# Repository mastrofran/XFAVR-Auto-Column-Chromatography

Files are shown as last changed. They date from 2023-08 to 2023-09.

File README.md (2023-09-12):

<p align="center">
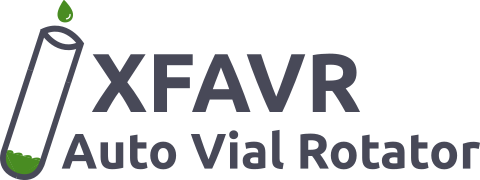
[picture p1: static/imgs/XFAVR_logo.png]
    
</p>
<br>

#### What is it?
XFAVR (Xander and Francesco's Auto Vial Rotator) is a column chromatography device written in C++ and controlled using a programmable microcontroller, such as an Arduino. This device can automatically rotate vials for fractionated liquid collected at a predefined rate of rotation and is primarily used to convert manual silica gel chromatography columns into automated pieces of equipment for research labs.

#### Who can use this?
Absolutely anyone. By following the detailed [**documentation**](https://xfavr.org), anyone can automate fractionated vial collection off of a manual silica column (or any other device that requires manual capture of fractionated liquid using vials).

#### What is involved?
As outlined in the [**documentation**](https://xfavr.org), this device can be built in a few hours using a combination of 3D printing, microcontroller assembly, and software installation.

# Software:

### Install:

#### Project Files:
To begin, please clone this repository using the following command:
```
git clone https://github.com/mastrofran/XFAVR-Auto-Column-Chromatography.git
```

- The [**XFAVR program**](/Code/XFAVR_Code/XFAVR_Code.ino) that runs on the programmable microcontroller to control the device is located in the [Code/XFAVR_Code](/Code/XFAVR_Code) subfolder and was written using C++.

#### Arduino Program:
Download the [official Arduino software](https://www.arduino.cc/en/software) for your computer operating system.

- The recommended way to run the XFAVR program on an programmable microcontroller is to download the official programmable microcontroller program for your chosen computer operating system. This program is used to communicate with programmable microcontroller microcontroller via a computer. Detailed instructions on how to use this program are provided in the documentation.

#### Cura Slicer:
Download the [official Cura Slicer](https://ultimaker.com/software/ultimaker-cura/) for your computer operating system.

- A 3D slicer program is needed to convert the XFAVR device STL files to gcode, which the 3D printer uses as a set of instructions for printing. Detailed instructions on how to use this program are provided in the [**documentation**](https://xfavr.org).

# Hardware:
A list of materials needed for this project are located in the [**documentation**](https://xfavr.org). 

Notes:
- Any microcontroller can be used for this project in theory, however the [Elegoo MEGA R3](https://www.amazon.com/ELEGOO-ATmega2560-ATMEGA16U2-Arduino-Compliant/dp/B01H4ZDYCE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) microcontroller is the recommended microcontroller for this project due to the number of available Digital I/O and Analog Input Pins.
- A 3D printer is used to print the parts. Any 3D printer will do as long as the printer bed dimensions can fit the parts. We used the [Ender-5 Plus](https://www.creality.com/products/ender-5-plus-3d-printer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) and the [Ender-3 v2 3D](https://www.creality.com/products/ender-3-v2-3d-printer-csco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)  printers for this project printer for this project.

⚠️ **WARNING: Do not change the dimensions of any part contained in the 3D printer STL files or the pieces may not fit together during assembly.**

# Documentation:
Official documentation is located here: [**DOCS**](https://xfavr.org)  

There are 3 main components to this project:

1. 3D printed components and assembly
2. Microcontroller assembly
3. Installing the XFAVR software onto the microcontroller

Detailed instructions are outlined in the [**documentation**](https://xfavr.org).

## Support:
Having trouble? Create an issue [here](https://github.com/mastrofran/XFAVR-Auto-Column-Chromatography/issues/new).

## Contributors:
Francesco Mastrocinque: [Github](https://github.com/mastrofran) | [LinkedIn](https://www.linkedin.com/in/francesco-mastrocinque)

Xander Wilcox: [Github](https://github.com/XanderWilcox) | [LinkedIn](https://www.linkedin.com/in/xander-wilcox-01321a21b)

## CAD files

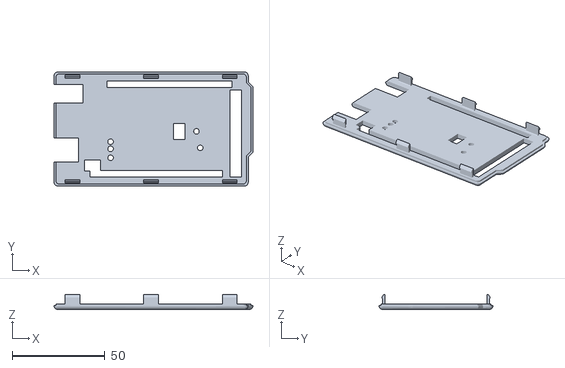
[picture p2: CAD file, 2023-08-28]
3D Printing Files/MicrocontrollerLid.stl
107.1 x 61.3 x 8.00

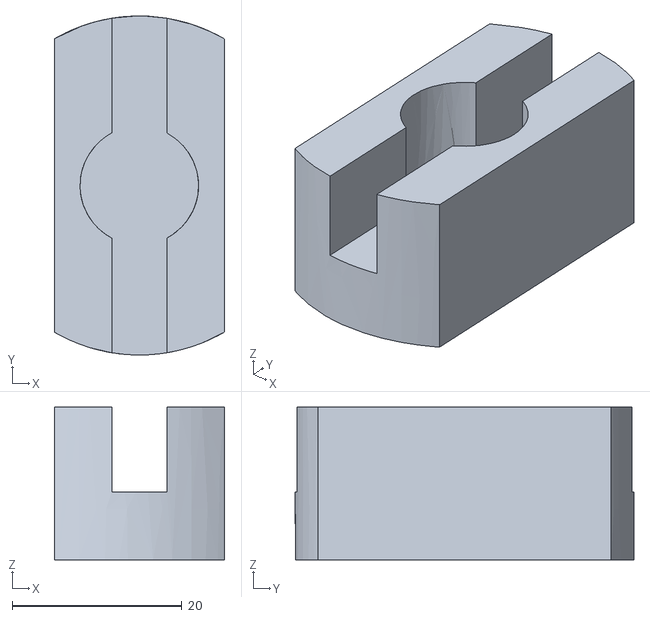
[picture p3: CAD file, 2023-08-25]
3D Printing Files/SingleStepperMotorAdapter.stl
20.1 x 40.0 x 18.0

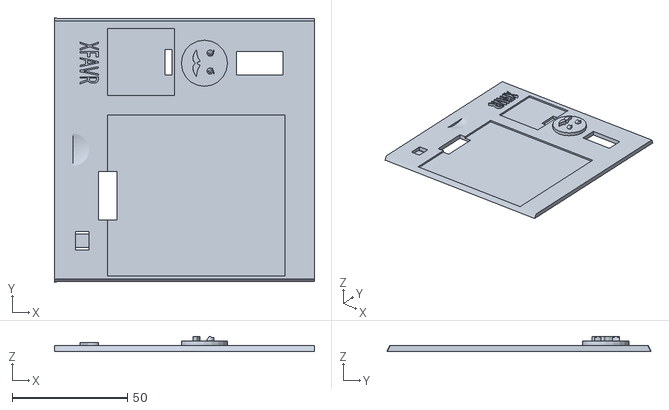
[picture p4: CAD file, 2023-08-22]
3D Printing Files/CaseLid.stl
112.8 x 114.8 x 6.50

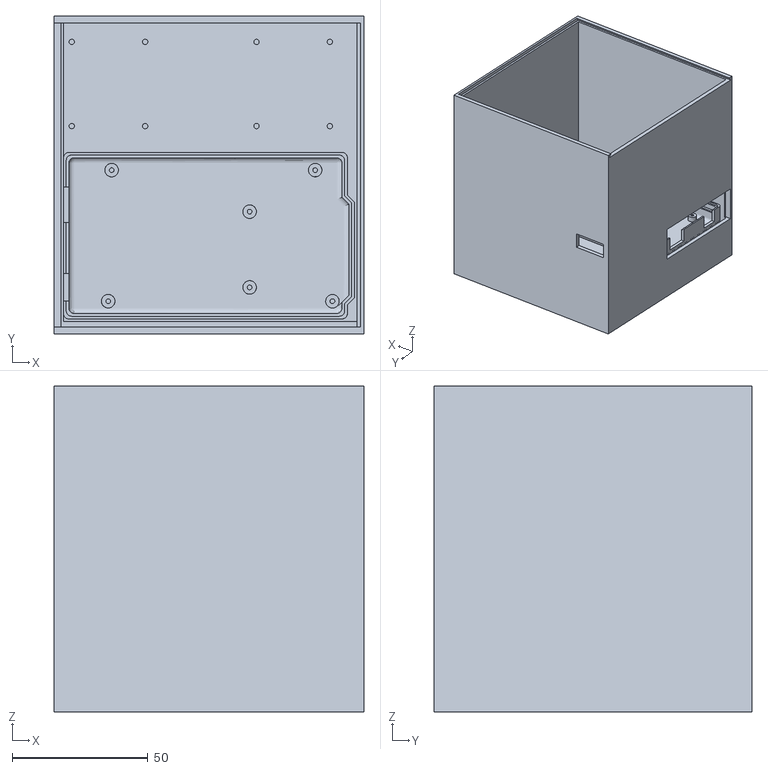
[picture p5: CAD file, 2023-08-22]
3D Printing Files/CaseBase.stl
114.0 x 117.0 x 120.0

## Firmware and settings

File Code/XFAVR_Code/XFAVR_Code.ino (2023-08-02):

//Includes the Arduino Stepper Library
#include <Stepper.h>

//Includes Libraries for OLED Screen
#include <SPI.h>
#include <Wire.h>
#include <Adafruit_GFX.h>
#include <Adafruit_SSD1306.h>
# include <Keypad.h>

// Declaration for an SSD1306 display connected to I2C (SDA, SCL pins)
// The pins for I2C are defined by the Wire-library. 
// On an arduino UNO:       A4(SDA), A5(SCL)
// On an arduino MEGA 2560: 20(SDA), 21(SCL)
// On an arduino LEONARDO:   2(SDA),  3(SCL), ...
#define OLED_RESET     -1 // Reset pin # (or -1 if sharing Arduino reset pin)
#define SCREEN_ADDRESS 0x3C ///< See datasheet for Address; 0x3D for 128x64, 0x3C for 128x32
#define SCREEN_WIDTH 128 // OLED display width, in pixels
#define SCREEN_HEIGHT 64 // OLED display height, in pixels

Adafruit_SSD1306 display(SCREEN_WIDTH, SCREEN_HEIGHT, &Wire, OLED_RESET);


//Constants for Loop Sequences, relevant for stepper motor and keypad
const float numVials = 16;
const float stepsPerRevolution_Vial = 2048;
const float stepsPerRevolution_Valve = 2048;
float stepsPerVial = (stepsPerRevolution_Vial / numVials);
float stepsPerValve = (stepsPerRevolution_Valve / 4);
int counter = 1;
unsigned long start_millis;
unsigned long current_millis;
boolean on = false;
unsigned long start_delay;
unsigned long screen_delay;

// Creates an instance of stepper class
// Pins entered in sequence IN1-IN3-IN2-IN4 for proper step sequence
Stepper vial_rotator = Stepper(stepsPerVial, 22, 24, 23, 25);
Stepper valve_rotator = Stepper(stepsPerValve, 50, 52, 51, 53);


String inputString;
long inputInt;


//Begin setting pins for Keypad
const byte ROWS = 4;
const byte COLS = 4;

char hexaKeys[ROWS][COLS] = {
  {'1', '2', '3', 'A'},
  {'4', '5', '6', 'B'},
  {'7', '8', '9', 'C'},
  {'*', '0', '#', 'D'}
};

byte rowPins[ROWS] = {A7, A6, A5, A4};
byte colPins[COLS] = {A3, A2, A1, A0};

Keypad customKeypad = Keypad(makeKeymap(hexaKeys), rowPins, colPins, ROWS, COLS);
//---------------------------------------------------------------------------//


void setup() {
  vial_rotator.setSpeed(50);
  valve_rotator.setSpeed(20);
  Serial.begin(9600);
  display.begin(SSD1306_SWITCHCAPVCC, SCREEN_ADDRESS);

  display.clearDisplay();

  display.setTextSize(3);
  display.setTextColor(WHITE);
  display.setCursor(1, 16);
  display.println("Welcome");


  display.display();
  delay(2000);
  screen_delay=0;
}


void loop()
{
  if (on == false){
    display.setTextSize(2);
    display.setTextColor(WHITE);
    display.setCursor(1, 16);
    display.println("Awaiting");
    display.println("Input");
    display.display();
    if (current_millis-screen_delay>1000){
      display.clearDisplay();
      display.setCursor(1, 16);
      display.println("Awaiting");
      display.println("Input...");
      display.display(); 
    }
    if(current_millis-screen_delay>2000){
      display.clearDisplay();
      screen_delay=current_millis;
    }
  
  }
  else{
    display.clearDisplay();
    display.setTextSize(1);
    display.setTextColor(WHITE);
    display.setCursor(0, 0);
    String vial_prefix = "Seconds/Vial : ";
    String runtime_prefix = "Vial Runtime (s): ";
    String counter_prefix = "Vial Number: ";
    String time_remaining= "Time Remain (m): ";
    display.print(vial_prefix);
    display.println(inputInt);
    display.println("");
    
    display.print(runtime_prefix);
    display.println(int((current_millis-start_millis)/1000)+1);
    display.println("");
    
    display.print(counter_prefix);
    display.println(counter);
    display.println("");
    
    display.print(time_remaining);
    display.println(float(inputInt*(numVials-counter)/60), 1);
    display.println("");

    display.display();
  }
  
  char key = customKeypad.getKey();
  if (key) {
    Serial.println(key);

    if (key >= '0' && key <= '9') {     // only act on numeric keys
      inputString += key;               // append new character to input string
    } else if (key == '#') {
      if (inputString.length() > 0) {
        inputInt = inputString.toInt(); // YOU GOT AN INTEGER NUMBER
        inputString = "";               // clear input
        start_millis = millis();

      }
    } else if (key == '*') {
      inputString = "";                 // clear input
    }
  }

  current_millis = millis();
//  Serial.println(inputInt);


  if (key == 'A') {
    on = !on;
    Serial.println(on);
    // turn valve to open position
    for (int x = 0; x < stepsPerValve; x++)
    {
      valve_rotator.step(-1);
    }
    Serial.println("should open from initial closed position");
    delay(2000);

  }
  if (current_millis - start_millis >= inputInt * 1000) {
    if (counter <= 16 && on == true) {
//      Serial.println(counter);
      // turn valve to close position before rotation
      for (int x = 0; x < stepsPerValve; x++)
      {
        valve_rotator.step(-1);
      }
      Serial.println("should close before rotation");
      delay(2000);
      if (counter < 16 && on == true) {
        // turn vial rotator (except last rotation; we don't to contaminate vial 1!)
        for (int x = 0; x < stepsPerVial; x++)
        {
          vial_rotator.step(-1);
        }
        //turn valve to open position after rotation
        for (int x = 0; x < stepsPerValve; x++)
        {
          valve_rotator.step(-1);
        }
        Serial.println("should open after rotation");
        delay(2000);
      }
      counter++;
      start_millis = current_millis+6000;
//      inputInt=inputInt+6;
    }
  }
    Serial.println(current_millis-start_millis);
}

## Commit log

2023-08-22 Added 3D Printing Files directory
2023-08-22 added 3D Printing Files
    [ArduinoBoxLid.stl, ArduinoBoxLower.stl, StepperMotorAdapter.stl]
2023-08-24 changed pivot arm top name
2023-08-25 swapped stepper motor adapter file
    [SingleStepperMotorAdapter.stl, StepperMotorAdapter.stl]
2023-08-28 Added microcontroller lid file
    [CaseBase.stl, CaseLid.stl, MicrocontrollerLid.stl]
2023-08-28 added 3D printer links to readme
